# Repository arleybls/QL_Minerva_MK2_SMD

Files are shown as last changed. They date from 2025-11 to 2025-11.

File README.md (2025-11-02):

# SINCLAIR QL - SMD Minerva MK II - New OS + RTC
SMD clone of the Board of ROM + RTC for Sinclair QL Computer

License under: CERN Open Hardware Licence Version 2 - Strongly Reciprocal

This work is based on Alavaro's Alea Revision that can be found here:
https://github.com/alvaroalea/QL_Minerva_MK2

Please also refer to the original repository and source to find the images for both the GAL and the ROM.

/RTC Tester is a PCF8583 verifier based on arduino nano. Output on serial console. It will help to quickly
sort out broken chips when sourcing.

m2

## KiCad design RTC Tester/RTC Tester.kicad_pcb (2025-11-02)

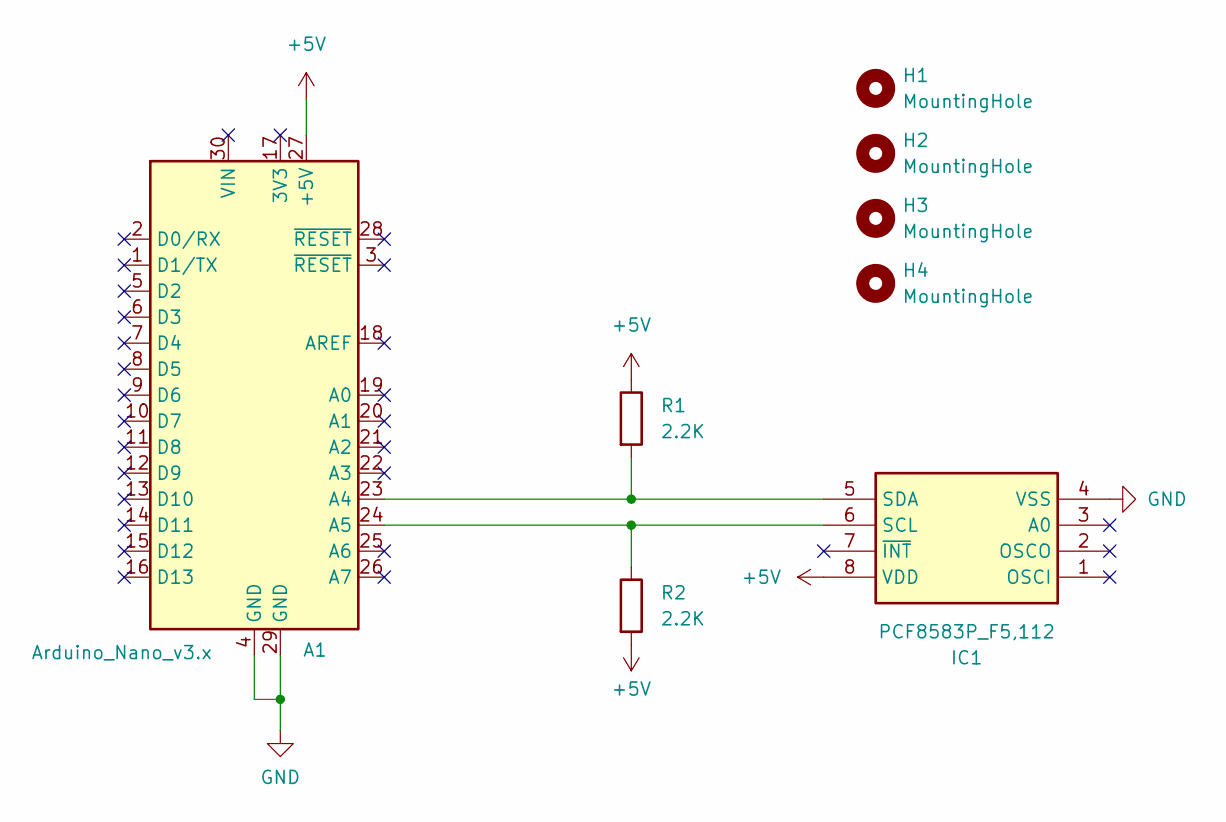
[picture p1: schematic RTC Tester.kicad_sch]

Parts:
A1: Arduino_Nano_v3.x; Arduino_Nano
H1, H2, H3, H4: MountingHole; MountingHole_3.2mm_M3
IC1: PCF8583P_F5,112; ZIF16_TO_PCF8583; Mouser Part Number 771-PCF8583PN
R1, R2: 2.2K; R_Axial_DIN0207_L6.3mm_D2.5mm_P10.16mm_Horizontal

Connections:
+5V: A1.27 (+5V), IC1.8 (VDD), R1.1, R2.2
GND: A1.4 (GND), A1.29 (GND), IC1.4 (VSS)
unnamed: A1.23 (A4), IC1.5 (SDA), R1.2
unnamed: A1.24 (A5), IC1.6 (SCL), R2.1

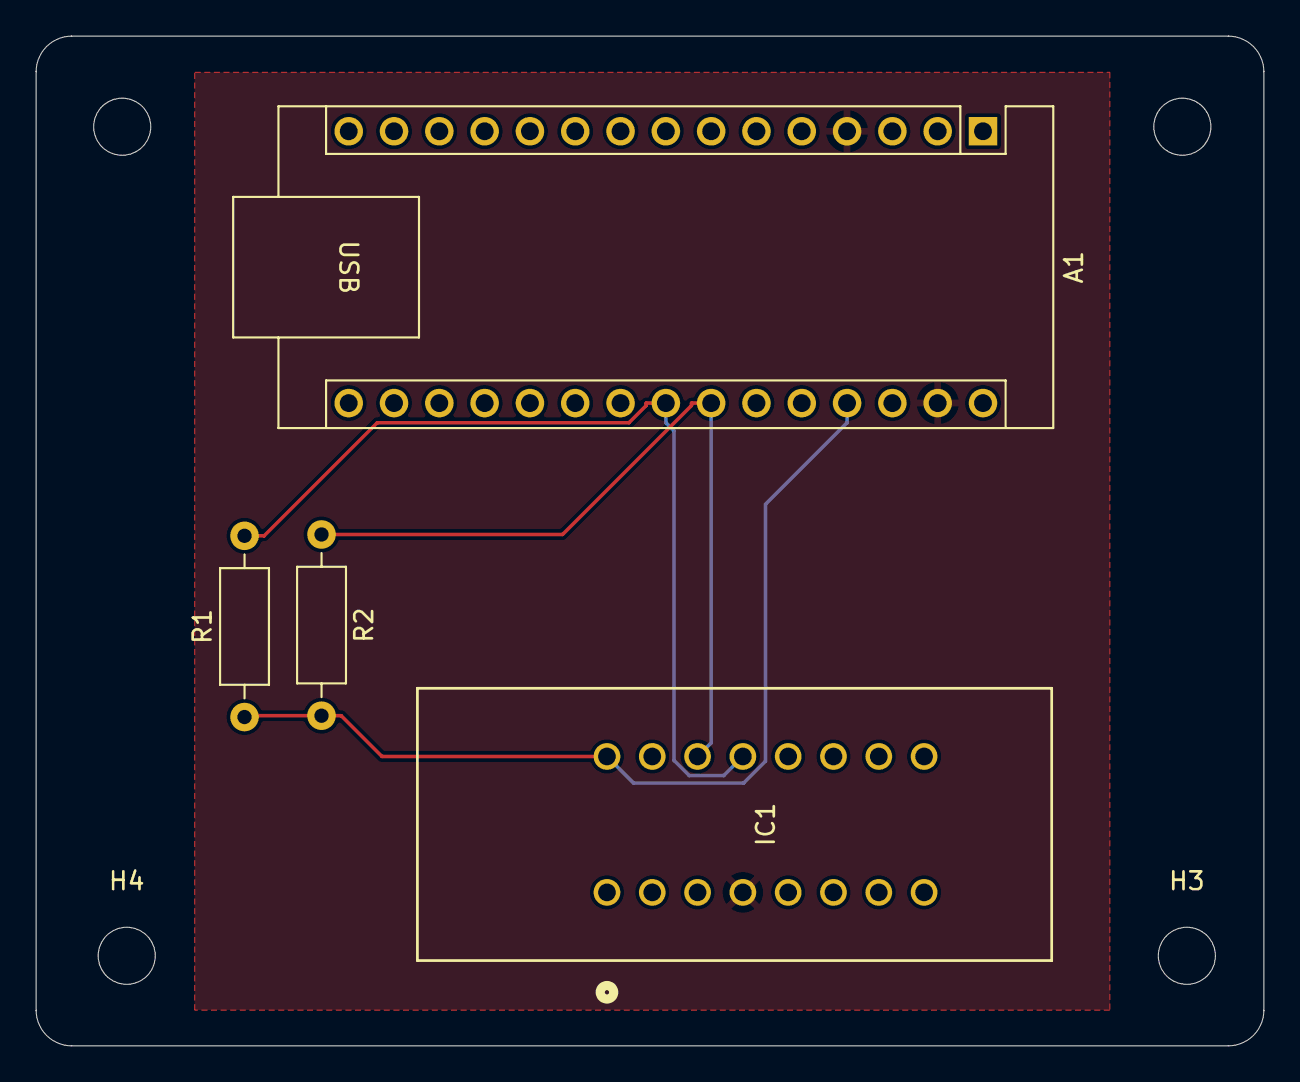
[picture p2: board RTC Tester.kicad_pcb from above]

Board: 2 copper layers, 68.8 x 56.6 mm, 8 parts (0 on the bottom side), 4 nets.

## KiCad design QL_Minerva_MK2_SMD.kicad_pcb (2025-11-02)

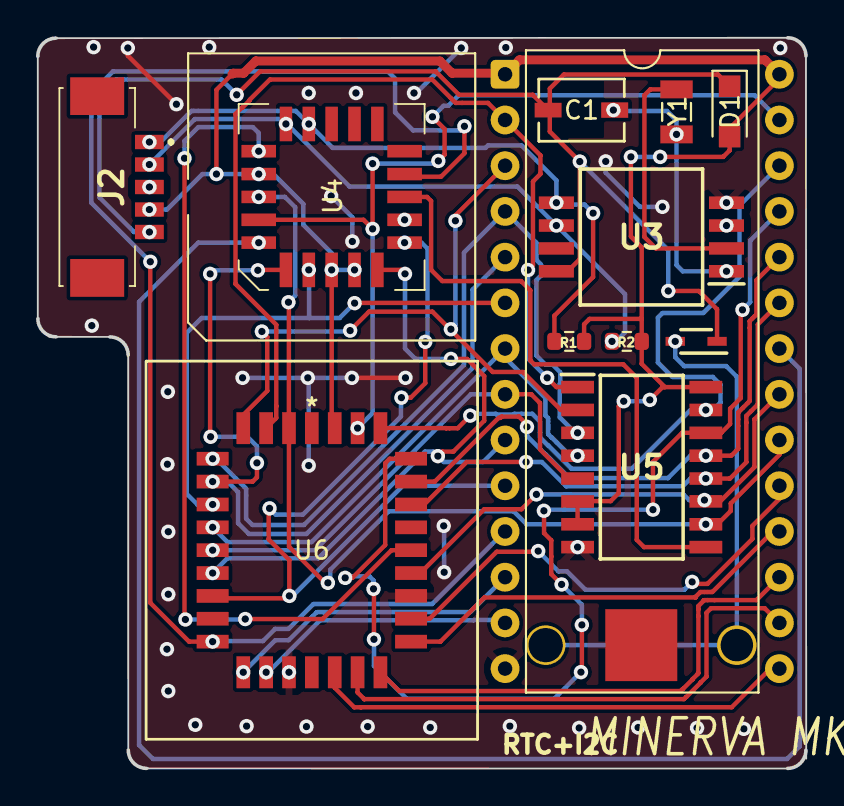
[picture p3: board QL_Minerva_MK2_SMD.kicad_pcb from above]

Board: 2 copper layers, 42.7 x 40.6 mm, 13 parts (0 on the bottom side), 35 nets.

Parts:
C1: 30p Variable; TZC3_MUR
D1: BAT42; Nexperia_CFP3_SOD-123W
D2: BAT42; BAT42WS
J1: Conn_01x02_Pin; CR927Holder
J2: Conn_01x05_Pin; PicoBlade_53261
R1, R2: 2K2; R_0603_1608Metric
U1: Socket to QL; DIP-28_W15.24mm
U3: PCF8583P; PCF8583T
U4: GAL16V8; PLCC-20_SMD-Socket
U5: 74LS133; SN74ALS133NSR
U6: 27C512PLCC; CONN_PLCC-32-AT-SMT_ADM
Y1: 32.768 kHz; XTAL_FC-135_32.7680KA-A0

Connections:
+5V: D1.2 (A), J2.4, R1.1, R2.1, U1.1 (A15), U1.28 (VCC), U4.6 (I6), U4.7 (I7), U4.20 (VCC), U5.6, U5.7, U5.16 (VCC), U6.32 (VCC)
/A0: U1.10 (A0), U4.9 (I9), U6.11 (A0)
/A1: U1.9 (A1), U4.8 (I8), U6.10 (A1)
/A2: U1.8 (A2), U5.5, U6.9 (A2)
/A3: U1.7 (A3), U5.4, U6.8 (A3)
/A4: U1.6 (A4), U4.5 (I5), U6.7 (A4)
/A5: U1.5 (A5), U4.4 (I4), U6.6 (A5)
/A6: U1.4 (A6), U5.3, U6.5 (A6)
/A7: U1.3 (A7), U5.2, U6.4 (A7)
/A8: U1.25 (A8), U5.14, U6.29 (A8)
/A9: U1.24 (A9), U5.13, U6.28 (A9)
/A10: U1.21 (A10), U5.11, U6.24 (A10)
/A11: U1.23 (A11), U5.12, U6.27 (A11)
/A12: U1.2 (A12), U5.1, U6.3 (A12)
/A13: U1.26 (A13), U5.15, U6.30 (A13)
/A14: U1.27 (A14), U4.2 (I2), U6.31 (A14)
/A15: U1.20 (~CE), U4.1 (I1/CLK), U5.10, U6.2 (A15)
/D0: U1.11 (D0), U4.12 (IO8), U6.13 (O0)
/D1: U1.12 (D1), U6.14 (O1)
/D2: U1.13 (D2), U6.15 (O2)
/D3: U1.15 (D3), U6.18 (O3)
/D4: U1.16 (D4), U6.19 (O4)
/D5: U1.17 (D5), U6.20 (O5)
/D6: U1.18 (D6), U6.21 (O6)
/D7: U1.19 (D7), U6.22 (O7)
/DECODE: U4.11 (I10/~OE), U5.9
/IC_ROMOE: U4.19 (IO1), U6.25 (~OE/VPP)
/K: C1.1, D1.1 (K), D2.1 (K), J2.5, U3.8 (Vdd)
/QL_ROMOE: U1.22 (~OE/Vpp), U4.3 (I3)
/SCL: J2.2, R2.2, U3.6 (SCL), U4.18 (IO2)
/SDA: J2.1, R1.2, U3.5 (SDA), U4.17 (I03)
GND: J1.2, J2.3, U1.14 (GND), U3.3 (A0), U3.4 (Vss), U4.10 (GND), U5.8 (GND), U6.16 (GND), U6.23 (~CE)
unnamed: D2.2 (A), J1.1
unnamed: C1.2, U3.1 (OSCI), Y1.1
unnamed: U3.2 (OSCO), Y1.2

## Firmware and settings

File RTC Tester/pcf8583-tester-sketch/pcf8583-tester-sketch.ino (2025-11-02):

#include <Wire.h>

#define PCF8583_ADDRESS 0x50  // Default I2C address

bool hasRun = false;
  int nDevices = 0;
//
byte testRAMAddr = 0x08;
byte testRAMValue = 0xAB;

// BCD to decimal conversion
int bcdToDec(byte val) {
  return ((val >> 4) * 10 + (val & 0x0F));
}

void setup() {
  Serial.begin(9600);
  Serial.print("\n\n----------------------------------------------\n");
  Wire.begin(9600);

  byte error, address;

  for (address = 1; address < 127; address++) {
    Wire.beginTransmission(address);
    error = Wire.endTransmission();

    if (error == 0) {
      Serial.print("> Device found at 0x");
      Serial.println(address, HEX);
      nDevices++;
    } else if (error == 4) {
      Serial.print("> Unknown error at 0x");
      Serial.println(address, HEX);
    };
  };

  if (!nDevices){
    Serial.println("> No I2C devices found");
  } else {
    // Set time to 12:34:56
    Wire.beginTransmission(PCF8583_ADDRESS);
    Wire.write(0x02); // Start at hundredths
    Wire.write(0x00); // hundredths
    Wire.write(0x56); // seconds (BCD 56)
    Wire.write(0x34); // minutes (BCD 34)
    Wire.write(0x12); // hours   (BCD 12)

    //Wire.write(0x12); // Hours
    Wire.endTransmission();

    // === Write test value to RAM ===
    Wire.beginTransmission(PCF8583_ADDRESS);
    Wire.write(testRAMAddr);        // RAM address
    Wire.write(testRAMValue);       // Test value
    Wire.endTransmission();
    delay(100);  // Wait a bit before reading

    // === Read back RAM value ===
    Wire.beginTransmission(PCF8583_ADDRESS);
    Wire.write(testRAMAddr);
    Wire.endTransmission();
    Wire.requestFrom(PCF8583_ADDRESS, 1);
    byte readValue = Wire.read();

    // === Compare and report ===
    Serial.print("> RAM Test - Written: 0x");
    Serial.print(testRAMValue, HEX);
    Serial.print(" | Read: 0x");
    Serial.println(readValue, HEX);

    if (readValue == testRAMValue) {
      Serial.println("> RAM test PASSED!");
    } else {
      Serial.println("> RAM test FAILED!");
    }
    delay(500);
  };
}

void loop() {

  if (!hasRun && nDevices) {
    hasRun = true;

    // Optional: print time every 2s
    Wire.beginTransmission(PCF8583_ADDRESS);
    Wire.write(0x03);
    Wire.endTransmission();

    Wire.requestFrom(PCF8583_ADDRESS, 3);
    byte secBCD = Wire.read();  // Seconds
    byte minBCD = Wire.read();  // Minutes
    byte hourBCD = Wire.read() & 0x3F; // Mask upper bits; // Hours

    int sec = bcdToDec(secBCD);
    int min = bcdToDec(minBCD);
    int hr  = bcdToDec(hourBCD);

    Serial.print("Time: ");
    if (hr < 10) Serial.print("0");
    Serial.print(hr); Serial.print(":");

    if (min < 10) Serial.print("0");
    Serial.print(min); Serial.print(":");

    if (sec < 10) Serial.print("0");
    Serial.println(sec);

    delay(2000);
    //
    //
  } else {
    Serial.print("\n> Reset to run again!");
    while(true);
  }

}

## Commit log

2025-11-02 Main files
    Added main files
    [QL_Minerva_MK2_SMD-B_Cu.gbr, QL_Minerva_MK2_SMD-B_Mask.gbr, QL_Minerva_MK2_SMD-B_Paste.gbr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]
2025-11-02 Correct coments
    [QL_Minerva_MK2_SMD.kicad_pcb]
2025-11-02 RTC Tester
    RTC Tester
    [RTC Tester-B_Cu.gbr, RTC Tester-B_Mask.gbr, RTC Tester-B_Paste.gbr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]
